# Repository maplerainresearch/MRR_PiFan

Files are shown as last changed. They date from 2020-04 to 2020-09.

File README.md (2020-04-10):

# MRR PiFan
Slim fan controller module for single board computers

For controlling the fan, you can use a script, like this one ([Pi Fan Controller](https://github.com/Howchoo/pi-fan-controller)).

The module can be used as a mini-hat too.

See this [blog post](https://teck78.blogspot.com/2020/04/mrr-pifan-slim-fan-controller-for.html) for more information.

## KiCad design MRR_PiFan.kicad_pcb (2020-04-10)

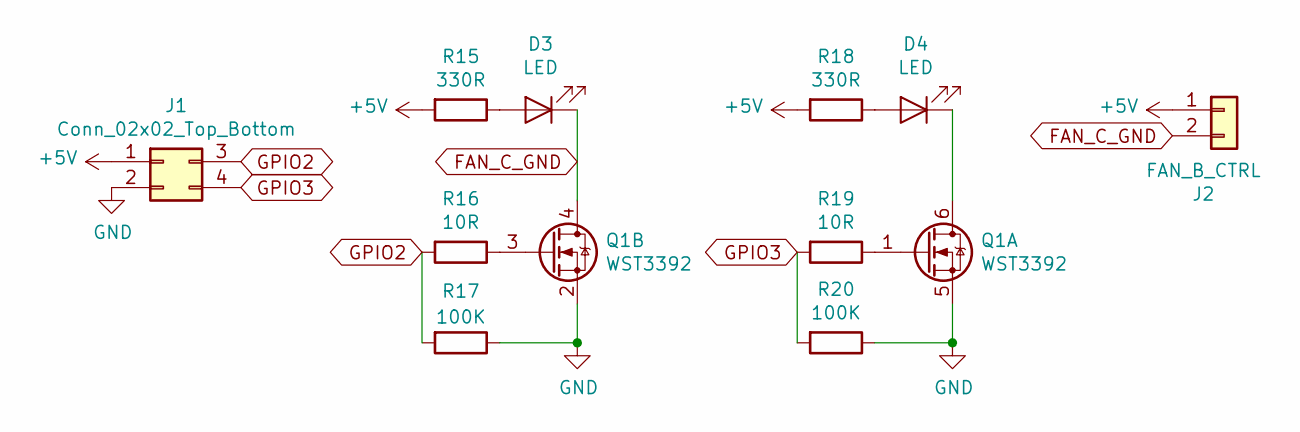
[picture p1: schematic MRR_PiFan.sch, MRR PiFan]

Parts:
D3, D4: LED; LED_0805_2012Metric_Pad1.15x1.40mm_HandSolder; Mfg part no. 17-21SURC/S530-A3/TR8; LCSC Part Number C72037
J1: Conn_02x02_Top_Bottom; PinSocket_2x02_P2.54mm_Vertical; Mfg part no. C47553; LCSC Part Number C47553
J2: FAN_B_CTRL; PinHeader_1x02_P2.54mm_Vertical; Mfg part no. MTB125-1102R1; LCSC Part Number C3761205
Q1: WST3392; SOT-23-6_Handsoldering; Mfg part no. WST3392; LCSC Part Number C148366
R15, R18: 330R; R_0805_2012Metric; Mfg part no. 0805W8F3300T5E; LCSC Part Number C17630
R16, R19: 10R; R_0805_2012Metric; Mfg part no. 0805W8F100JT5E; LCSC Part Number C17415
R17, R20: 100K; R_0805_2012Metric; Mfg part no. 0805W8F1003T5E; LCSC Part Number C149504

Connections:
+5V: J1.1, J2.1, R15.2, R18.2
FAN_C_GND: D3.1 (K), J2.2, Q1.4 (D)
GND: J1.2, Q1.2 (S), Q1.5 (S), R17.1, R20.1
GPIO2: J1.3, R16.2, R17.2
GPIO3: J1.4, R19.2, R20.2
unnamed: D3.2 (A), R15.1
unnamed: D4.1 (K), Q1.6 (D)
unnamed: D4.2 (A), R18.1
unnamed: Q1.1 (G), R19.1
unnamed: Q1.3 (G), R16.1

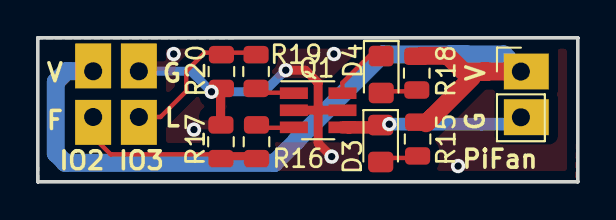
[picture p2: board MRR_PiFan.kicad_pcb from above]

Board: 2 copper layers, 30.0 x 8.0 mm, 11 parts (1 on the bottom side), 10 nets.

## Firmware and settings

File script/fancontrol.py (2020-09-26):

#!/usr/bin/env python3

import subprocess
import time

from gpiozero import OutputDevice


ON_THRESHOLD = 50 * 1000  # (degrees Celsius) Fan kicks on at this temperature.
OFF_THRESHOLD = 45 * 1000  # (degress Celsius) Fan shuts off at this temperature.
SLEEP_INTERVAL = 5  # (seconds) How often we check the core temperature.
GPIO_PIN = 2  # Which GPIO pin you're using to control the fan.
LED_PIN = 3  # Which GPIO pin you're using to control the LED.


def get_temp():
    """Get the core temperature.

    Read file from /sys to get CPU temp in temp in C *1000

    Returns:
        int: The core temperature in thousanths of degrees Celsius.
    """
    with open("/sys/class/thermal/thermal_zone0/temp") as f:
        temp_data = f.read()

    return int(temp_data)


if __name__ == '__main__':
    # Validate the on and off thresholds
    if OFF_THRESHOLD >= ON_THRESHOLD:
        raise RuntimeError('OFF_THRESHOLD must be less than ON_THRESHOLD')

    fan = OutputDevice(GPIO_PIN)
    led = OutputDevice(LED_PIN)

    led.on()
   
    while True:
        temp = get_temp()

        # Start the fan if the temperature has reached the limit and the fan
        # isn't already running.
        # NOTE: `fan.value` returns 1 for "on" and 0 for "off"
        if temp > ON_THRESHOLD and not fan.value:
            fan.on()
            led.off()

        # Stop the fan if the fan is running and the temperature has dropped
        # to 10 degrees below the limit.
        elif fan.value and temp < OFF_THRESHOLD:
            fan.off()
            led.on()

        time.sleep(SLEEP_INTERVAL)

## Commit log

2020-04-10 Added initial version
    [MRR_PiFan-B_Cu.gbl, MRR_PiFan-B_Mask.gbs, MRR_PiFan-B_Paste.gbp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]
2020-09-26 Added fan control scripts

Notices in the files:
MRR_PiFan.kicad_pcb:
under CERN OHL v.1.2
